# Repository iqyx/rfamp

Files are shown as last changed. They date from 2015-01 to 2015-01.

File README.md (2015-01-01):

RF amplifier&filter for 433MHz band (amateur balloon telemetry reception)
================================================================================

Component selection
------------------------

  * NCP700: 200 mA Low Noise RF Low Dropout Linear Voltage Regulator, Ultra Low Noise (typ 15 mV rms), Very High PSRR (typ 80 dB)
    ([http://www.onsemi.com/PowerSolutions/product.do?id=NCP700](http://www.onsemi.com/PowerSolutions/product.do?id=NCP700)),
    0.22€ in singles (farnell)

  * Epcos B3721 SAW filter for 433.92MHz ([http://www.epcos.com/epcos-en/529508/products/product-catalog/rf---saw-components-and-modules/automotive-electronics-remote-control/wideband-filters-for-ism](http://www.epcos.com/epcos-en/529508/products/product-catalog/rf---saw-components-and-modules/automotive-electronics-remote-control/wideband-filters-for-ism)),
    1.53€ in singles (farnell)

  * ADL5523 400 MHz TO 4000 MHz Low Noise Amplifier, 21.5dB gain, 0.8dB noise figure
    ([http://www.analog.com/en/rfif-components/rfif-amplifiers/adl5523/products/product.html](http://www.analog.com/en/rfif-components/rfif-amplifiers/adl5523/products/product.html))
    2.28€ in singles (farnell)

  * VCAS06AG183 AVX AntennaGuard - Multilayer Ceramic Transient Voltage Suppressors ESD Protection for Antennas and Low Capacitor Loading Applications
    ([http://avx.com/docs/Catalogs/aguard.pdf](http://avx.com/docs/Catalogs/aguard.pdf))
    0.118€ in singles (farnell)

  * some passives

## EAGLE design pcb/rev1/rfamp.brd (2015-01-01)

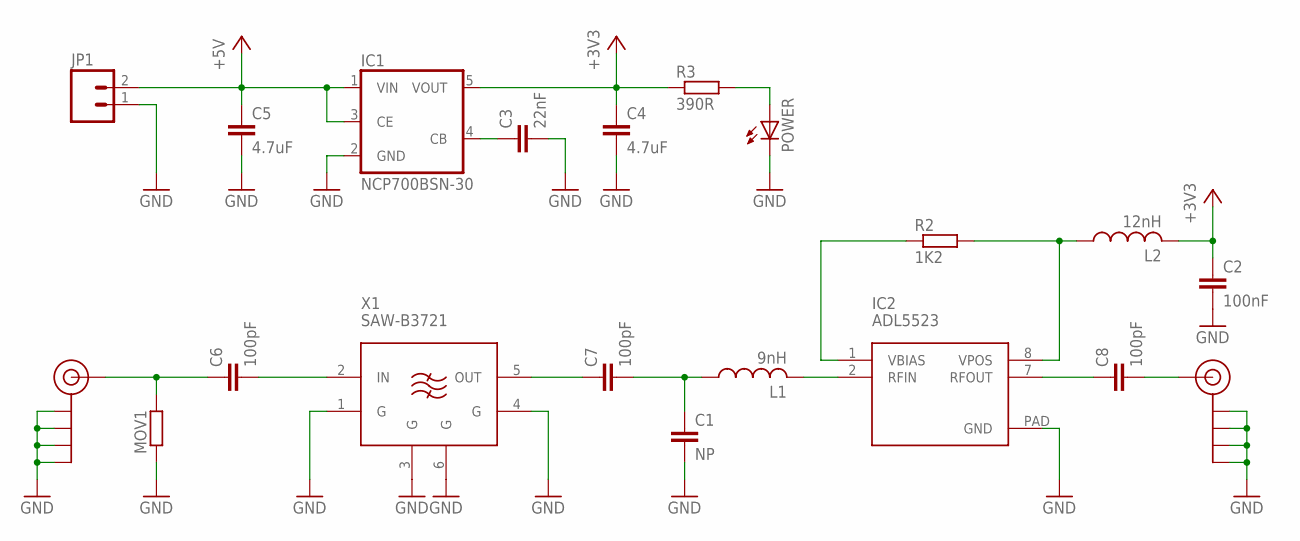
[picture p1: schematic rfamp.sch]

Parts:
C1: NP; C0603
C2: 100nF; C0603
C3: 22nF; C0603
C4, C5: 4.7uF; C0805
C6, C7, C8: 100pF; C0603
IC1: NCP700BSN-30; SOT25
IC2: ADL5523; LFCSP_VD_8
J$1, J$2: SMA_EDGE; SMA-EDGE
JP1: M02JST-PTH-2; JST-2-PTH
L1: 9nH; L2012C
L2: 12nH; L2012C
MOV1: R-EU_R0603; R0603
POWER: LEDCHIPLED_0603; CHIPLED_0603
R2: 1K2; R0603
R3: 390R; R0603
X1: SAW-B3721; B3721

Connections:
+3V3: C2.1, C4.1, IC1.5 (VOUT), L2.2, R3.1
+5V: C5.1, IC1.1 (VIN), IC1.3 (CE), JP1.2
GND: C1.2, C2.2, C3.2, C4.2, C5.2, IC1.2 (GND), IC2.PAD (GND), J$1.GND@0 (GND), J$1.GND@1 (GND), J$1.GND@2 (GND), J$1.GND@3 (GND), J$2.GND@0 (GND), J$2.GND@1 (GND), J$2.GND@2 (GND), J$2.GND@3 (GND), JP1.1, MOV1.1, POWER.C, X1.1 (G), X1.3 (G), X1.4 (G), X1.6 (G)
unnamed: C6.1, J$1.SIG (SIGNAL), MOV1.2
unnamed: C1.1, C7.2, L1.1
unnamed: IC2.8 (VPOS), L2.1, R2.2
unnamed: IC2.1 (VBIAS), R2.1
unnamed: IC2.2 (RFIN), L1.2
unnamed: C8.1, IC2.7 (RFOUT)
unnamed: POWER.A, R3.2
unnamed: C3.1, IC1.4 (CB)
unnamed: C6.2, X1.2 (IN)
unnamed: C7.1, X1.5 (OUT)
unnamed: C8.2, J$2.SIG (SIGNAL)

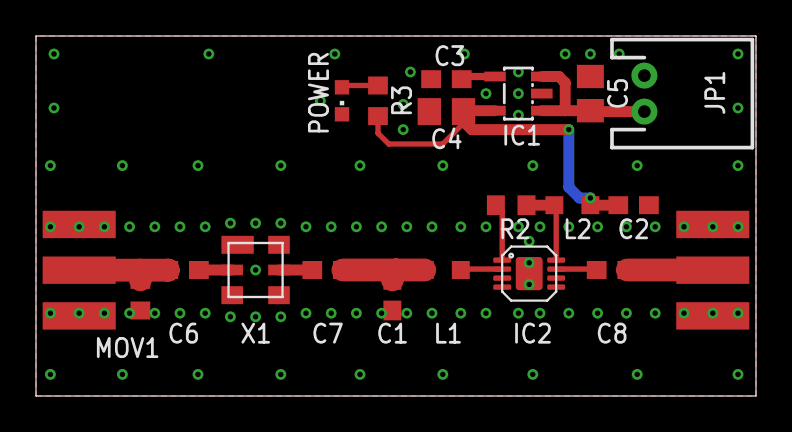
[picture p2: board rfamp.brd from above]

Board: 2 copper layers, 40.0 x 20.0 mm, 20 parts (0 on the bottom side), 14 nets.

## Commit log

2014-12-03 Add schematic + layout.
    [rfamp.brd, rfamp.sch]
2014-12-03 Minor changes.
    [rfamp.brd, rfamp.sch]
2014-12-03 Add board exports.
2014-12-03 Add schematic export.
2014-12-06 Fix board outline (move SMA conenctors to board edges).
    [rfamp.brd]
2014-12-06 Add SeeedStudio gerber outputs.
    [rfamp.GBL, rfamp.GBO, rfamp.GBP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]
2014-12-06 Replace SMA edge connectors.
    [rfamp.brd, rfamp.sch]
2014-12-06 SeeedStudio rev1.1 outputs.
    [rfamp.GBL, rfamp.GBO, rfamp.GBP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]
2014-12-06 Insert dc blocking capacitors.
    [rfamp.brd, rfamp.sch]
2014-12-06 Add rev1.2 SeeedStudio gerber exports.
    [rfamp.GBL, rfamp.GBO, rfamp.GBP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]
2015-01-01 Modified component values to match working prototype.
    [rfamp.brd, rfamp.sch]
2015-01-01 Add schematic annotation.
    [rfamp.sch]
2015-01-01 Regenerate schematic image output.

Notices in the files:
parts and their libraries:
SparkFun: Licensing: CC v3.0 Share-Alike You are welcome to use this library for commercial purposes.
